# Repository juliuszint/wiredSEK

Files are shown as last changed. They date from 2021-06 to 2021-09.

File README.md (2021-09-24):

# A wired version of the Surface Ergonomic Keyboard from Microsoft.

## Disassembly
**Disclaimer**: These disassembly instructions can not be reversed and result in a broke keyboard. They are only provided as a documentation for other people to read, so that they dont have to brick their keyboard. So with that out of the way lets get started.

The keyboard is held together by an awful lot of glue and some screws. I do not own a heat gun and so i started with carefully using a screwdriver to remove the wrist rest. Even with a heat gun i doubt that it is impossible, to remove it without damaging some plastic. As can be seen in the following image, there is not only glue on the edges, but also in the center of the wrist rest.

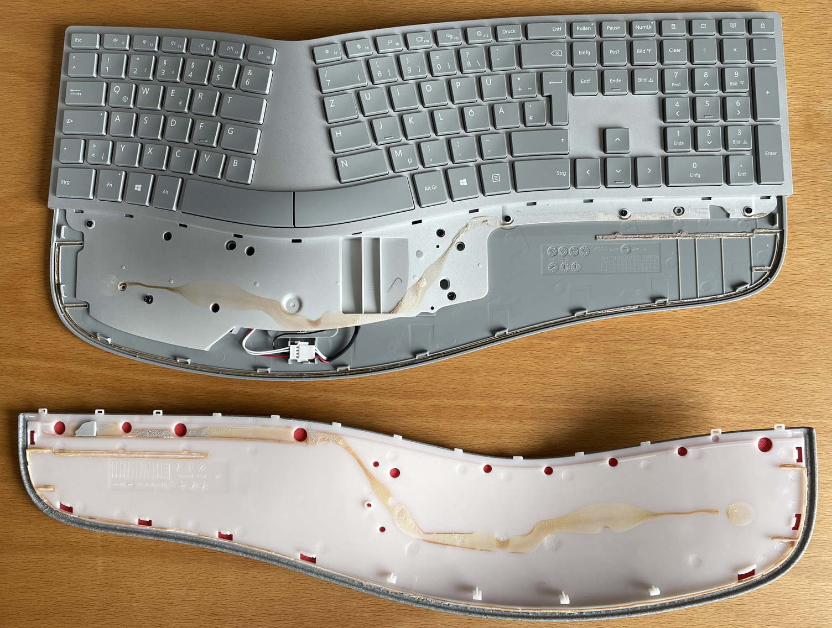
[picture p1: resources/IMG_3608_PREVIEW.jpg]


The next step is to remove all 10 screws. 4 of them are small and 6 are rather large and threaded into the plastic. Then disconnect the power and paring button connector from the logic board. Next up is getting the screw driver back out and start to remove the keyboard panel from the case. It is held in place by a glue stripe all around the edges, some glue right in the center of the keyboard, and 9 glue spots as one can see in the following image.

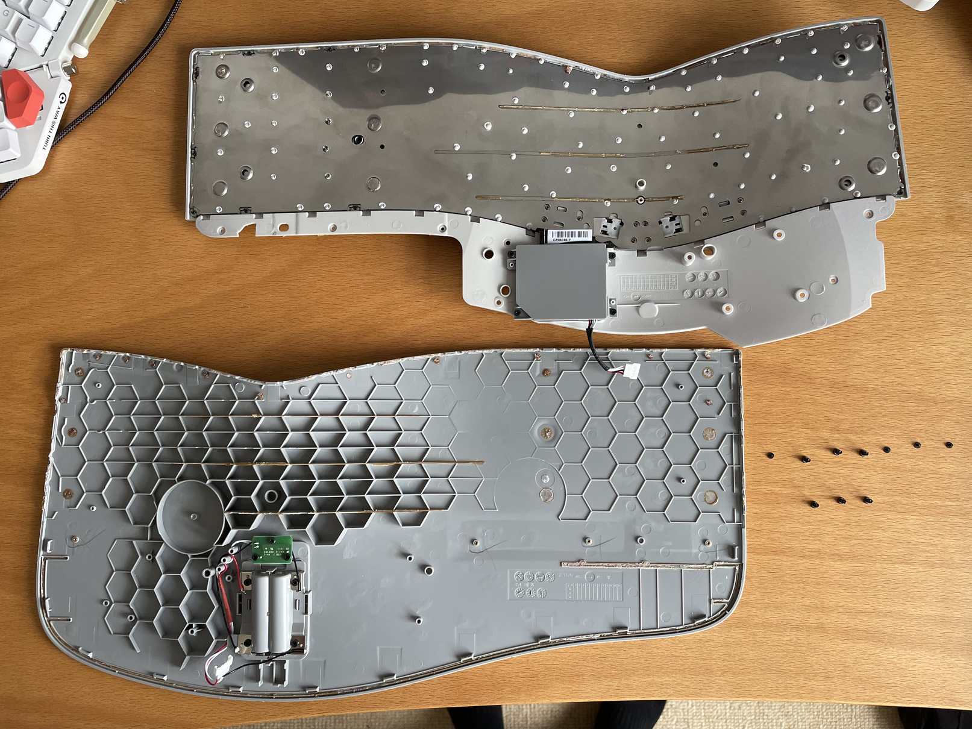
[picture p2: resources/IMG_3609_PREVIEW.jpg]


4 more large screws hold the logic board cover in place. With them removed we can lift up the logic board and see the 34 pin Flexible Flat Cable (FFC) that connects the keyboard matrix with the logic board. 2 of those 34 lanes are not routed, so only 32 are actually connected.

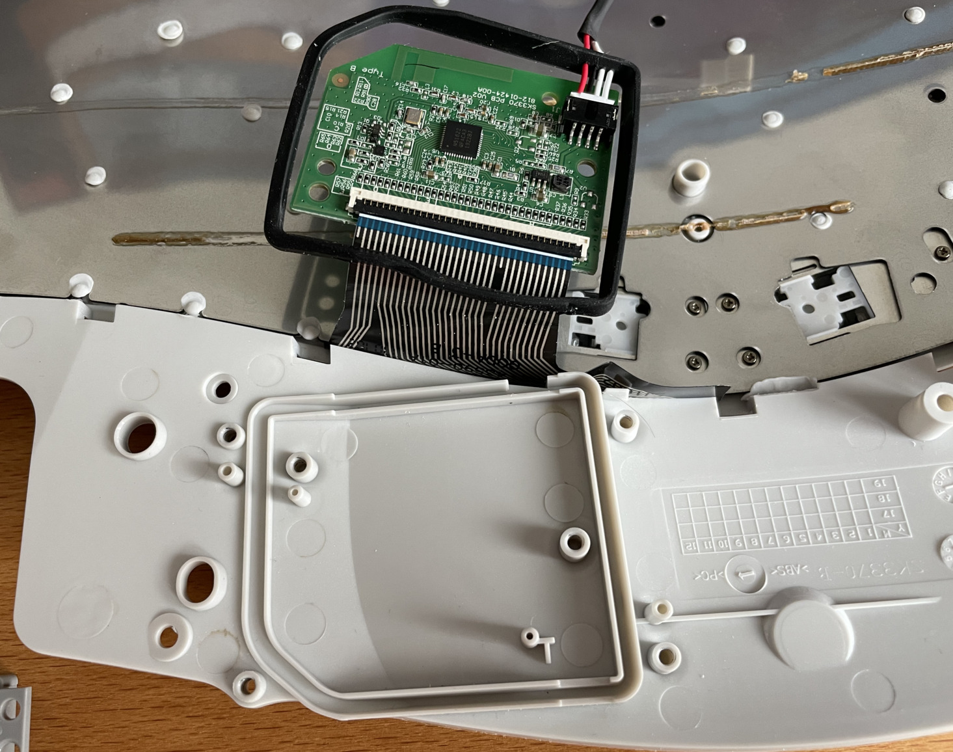
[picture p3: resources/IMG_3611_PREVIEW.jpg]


I hoped that by fully disassembling the keyboard, I would be able to learn more about the keyboard matrix, but this did not turn out to be true. Anyway, after i removed every single plastic rivet and removed the remaining screws, this is how a fully disassembled surface ergonomic keyboard looks like:

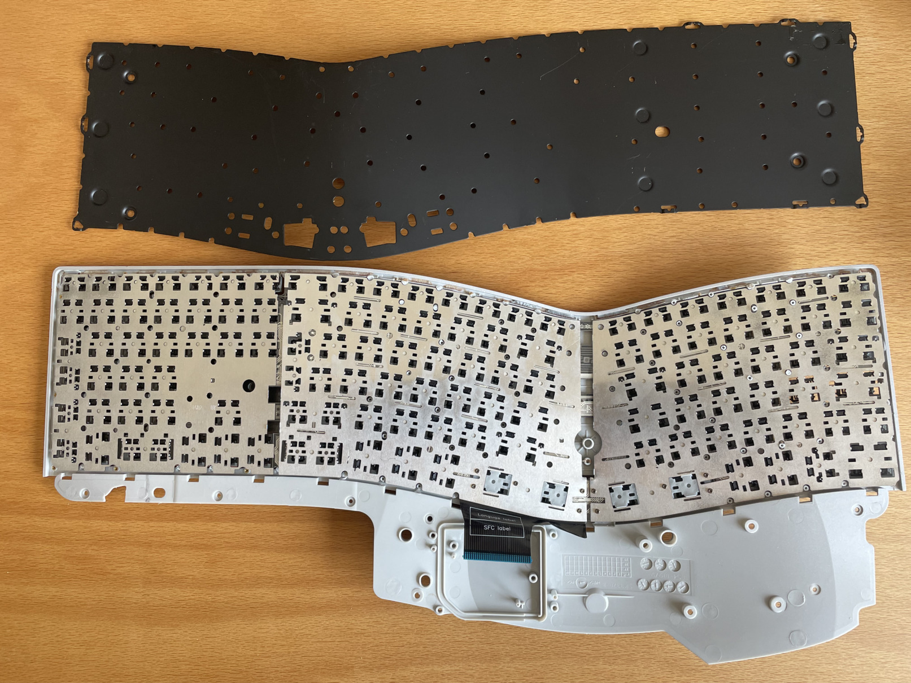
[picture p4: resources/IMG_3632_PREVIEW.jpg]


Once the metal backplate is removed, the keys can just be popped out. They are still kept in place by small metal sheets and the wires connecting them. With the keyboard fully disassembled, we can now start to measure the keyboard matrix.

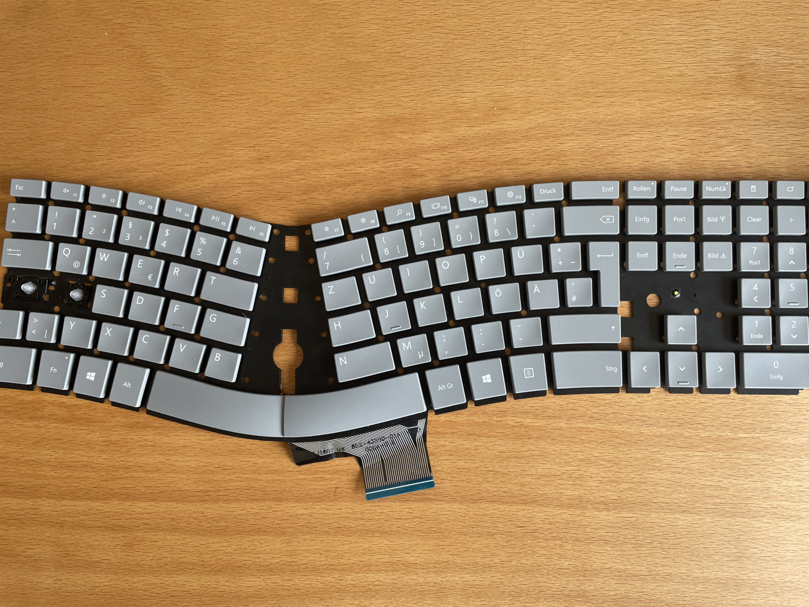
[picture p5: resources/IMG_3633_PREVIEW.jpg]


## Figuring out the keyboard matrix

With [@Geends](https://github.com/Geend/) logic analyzer and other hardware, we started by probing the logic level of every pin when no key is pressed. Next we toggled every LED (total of 4) one after another and observed the changes. Armed with that information we were able to make a educated guess of the keyboard matrix and with the 16 channel logic analyzer we were able to determine the full keyboard matrix.

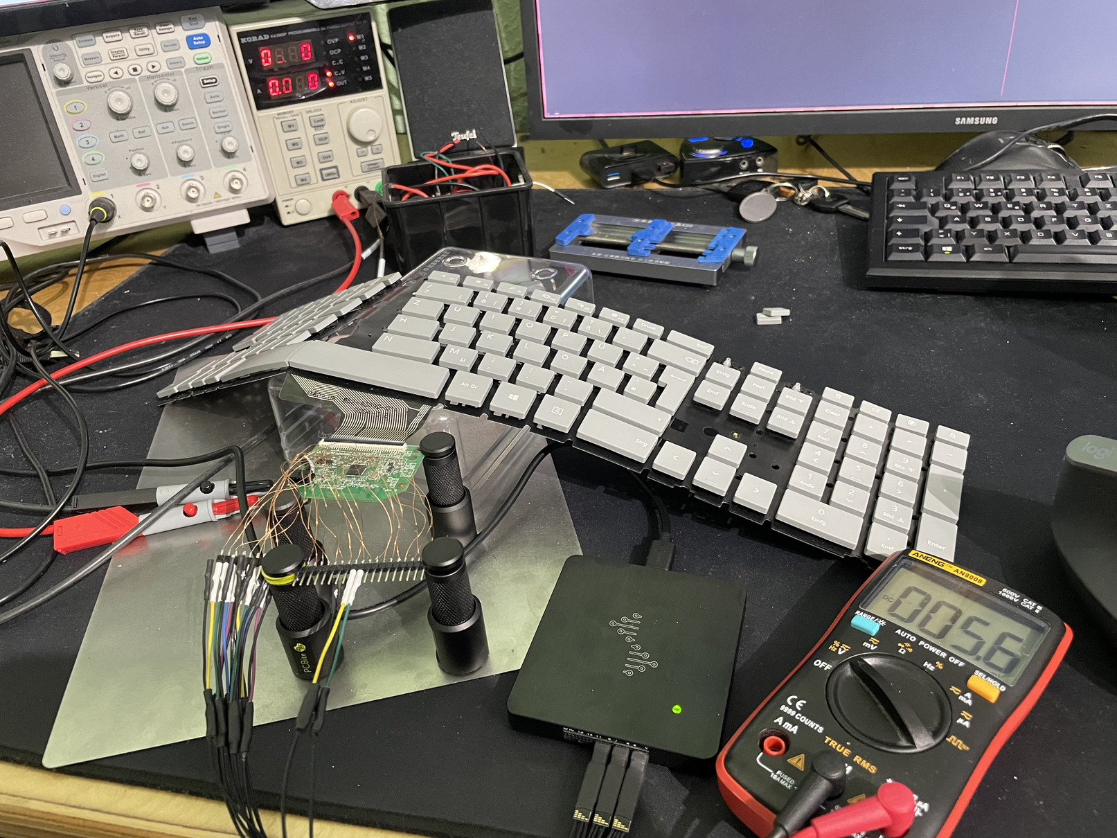
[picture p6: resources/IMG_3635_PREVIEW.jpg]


Initial testing results:

| Pin Number (top left = 0)| Logic Level without Keypress | Function |
|:---:|:---:| ---|
| 0 |3V | Keyboard Matrix: Row 0 |
| 1 |3V | Keyboard Matrix: Row 1 |
| 2 |3V | Keyboard Matrix: Row 2 |
| 3 |3V | Keyboard Matrix: Row 3 |
| 4 |3V | Keyboard Matrix: Row 4 |
| 5 |3V | Keyboard Matrix: Row 5 |
| 6 |3V | Keyboard Matrix: Row 6 |
| 7 |3V | Keyboard Matrix: Row 7 |
| 8 |3V | NumLink LED - with 3V the LED is off and on with 0.4V |
| 9 |3V | CapsLock LED - with 3V the LED is off and on with 0.4V |
| 10 |GND | Not connected |
| 11 |1V | Pairing LED - White |
| 12 |1V | Pairing LED - Red |
| 13 |3V | LED Vcc |
| 14 |0V | Keyboard Matrix: Column 0 |
| 15 |0V | Keyboard Matrix: Column 1 |
| 16 |0V | Keyboard Matrix: Column 2 |
| 17 |0V | Keyboard Matrix: Column 3 |
| 18 |0V | Keyboard Matrix: Column 4 |
| 19 |0V | Keyboard Matrix: Column 5 |
| 20 |0V | Keyboard Matrix: Column 6 |
| 21 |0V | Keyboard Matrix: Column 7 |
| 22 |0V | Keyboard Matrix: Column 8 |
| 23 |0V | Keyboard Matrix: Column 9 |
| 24 |0V | Keyboard Matrix: Column 10 |
| 25 |0V | Keyboard Matrix: Column 11 |
| 26 |0V | Keyboard Matrix: Column 12 |
| 27 |0V | Keyboard Matrix: Column 13 |
| 28 |0V | Keyboard Matrix: Column 14 |
| 29 |0V | Keyboard Matrix: Column 15 |
| 30 |0V | Keyboard Matrix: Column 16 |
| 31 |3V | Fn LED - with 3V the LED is off and on with 0.4V |
| 32 |3V | Rollen - with 3V the LED is off and on with 0.4V |
| 33 |GND | Not connected |

The keyboard matrix from Surface Ergonomic Keyboard with german keys:

| | Row-0 | Row-1 | Row-2 | Row-3 | Row-4 | Row-5 | Row-6 | Row-7 |
|:---:|:---:|:---:|:---:|:---:|:---:|:---:|:---:|:---:|
| Column-0  |Num Entf |Num 3 |Num 6 |Num 9 |Num \* |6 |V |L |
| Column-1  |Num 0 |Num 2 |Num 5 |Num 8 |Num / |5 |C |K |
| Column-2  |< |Num 1 |Num 4 |Num 7 |Calc |Num Enter |X |J |
| Column-3  |Y |T |R |E |W |Q |Pfeil oben  |H |
| Column-4  |- |Bild Unten  |Bild Hoch |Ende |Num Lock |Druck |F12 |Leer |
| Column-5  |. |F4 |Entf |Pos1 |Tab |Einfg |F11 |G |
| Column-6  |, |# |0 | |O |Num + |F10 |F |
| Column-7  |M |Ä |9 |+ |i |\` |F9 |D |
| Column-8  |N |Num - |8 |Ü |U |ß |F8 |S |
| Column-9  |Backspace |Arrow right |7 |P |Z |^ |F7 |A |
| Column-10 |Left Ctrl | | | |Right Ctrl  | | | |
| Column-11 | |Left Shift  | | | |Right Shift | |Fn |
| Column-12 | | |Left ALT | | | |Alt Gr |Context Menu|
| Column-13 |Pause |Rollen |Chat |Left WIN |Lock |Rechteck | |Right WIN |
| Column-14 |Num Clear |4 |F1 |F5 | |3 |Caps Lock |Arrow Down  |
| Column-15 | |F2 |F6 |Enter |F3 |2 | |Arrow Left  |
| Column-16 |Esc | | | | |1 |B |Ö |

## Designing the PCB

The most difficult part was to find a MCU due to the chip shortage. From all the compatible controllers that are listed on QMKs website only the AT90USB646 was available. This turned out to be a perfect fit. It is a very simple MCU with enough GPIO pins, USB and a 64-TQFP package can be soldered by hand.

There is not much to say about the schematic itself because there is not a lot more on it then the MCU and a USB jack. There are a lot of testpoints, a power LED that can be disabled with a solder jumper, a status LED and a JTAG interface.

The complete board was designed with the open source software Kicad and tutorials from the Youtube channel Phil's Lab. This [[2]] three hour video is a great resource if someone wants to learn how to create a board from scratch and have it manufactured.

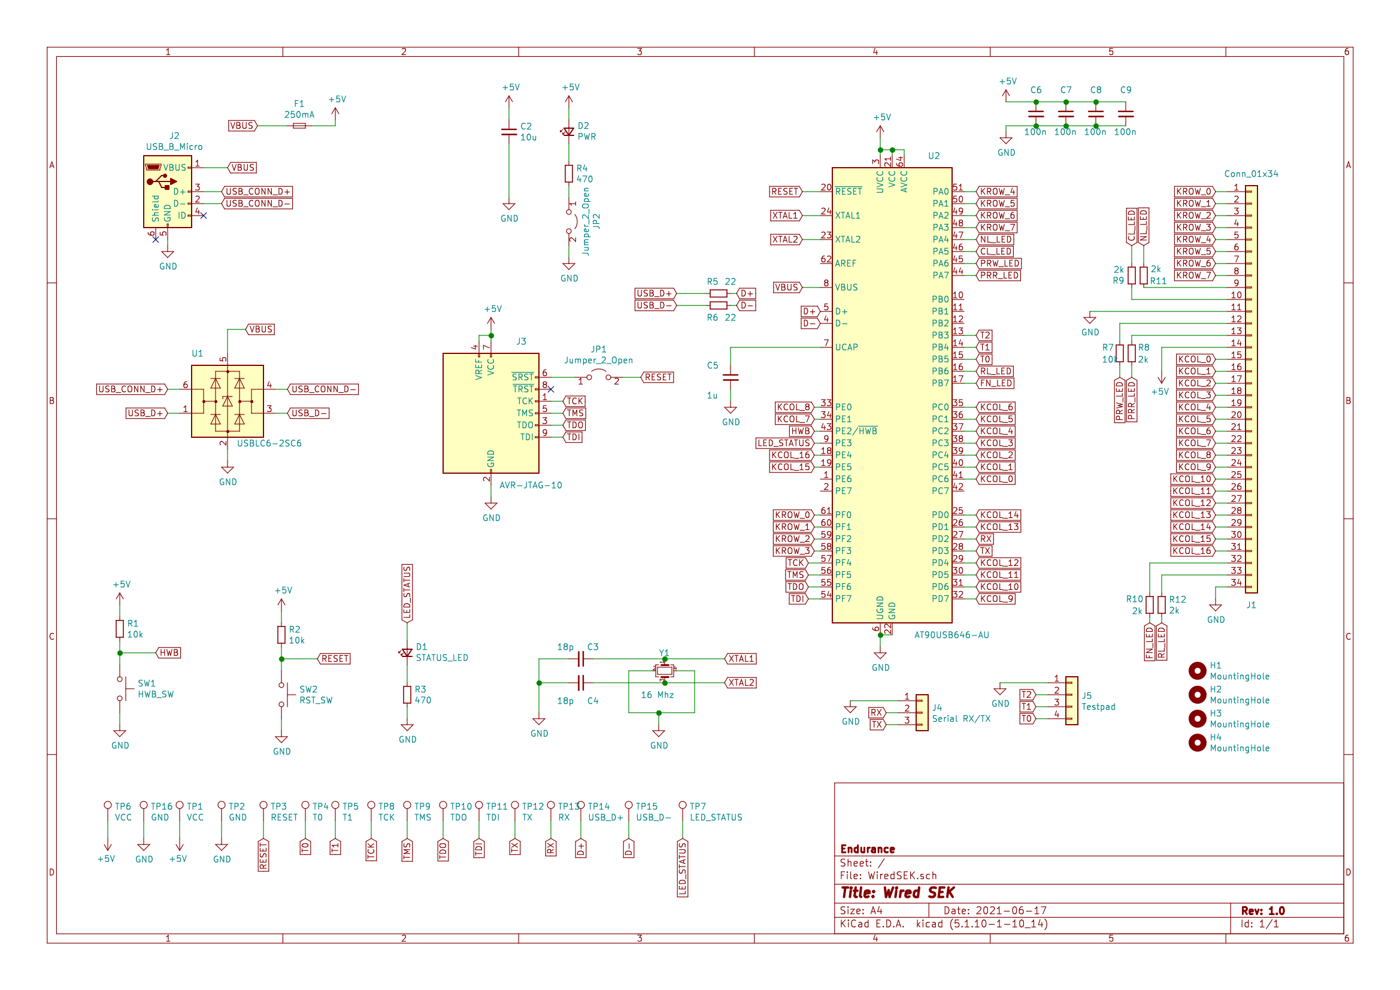
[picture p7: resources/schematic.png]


The outline and four holes (two placeholder and two for screws) are required for the circuit board to fit inside the keyboard. The position of the FFC/FPC connector is also fixed while the rest is up to us. 

The USB connector was the most difficult part to place. Because the keyboard is glued together and cannot be easily opened without damaging it, the plan is to make a small cutout where the PCB is located. So in a perfect world the connector would not need any more space than what is neccessary to switch the board. I managed this by using a right angle USB connector on the back of the PCB.

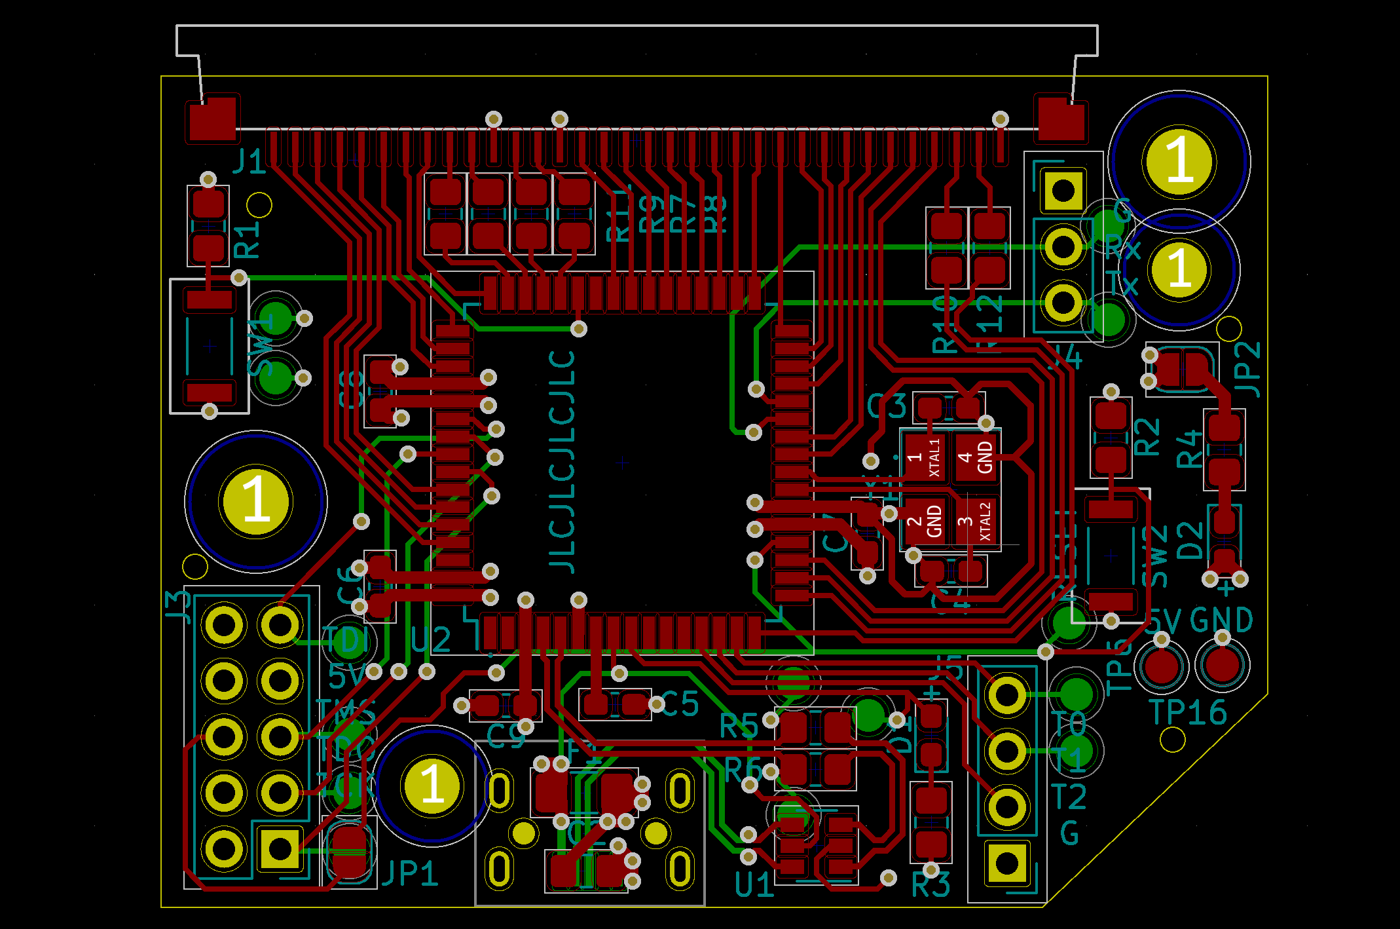
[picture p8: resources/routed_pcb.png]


## PCB assembly

The USB connector, the FFC/FPC connector and the MCU had to be soldered by hand. Everything else was done by JLCPCB. These were the exact parts that i ordered. I included the USB cable not only because i like completeness, but also because not every cable will work. Between the USB connector and the PCB is only a limited amount of space for the plug.

* [FFC/FPC Connector](https://www.digikey.de/product-detail/de/F52R-1A7H1-11034/609-F52R-1A7H1-11034DKR-ND/11564783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)
* [AT90USB646-AUR](https://www.digikey.de/product-detail/de/microchip-technology/AT90USB646-AUR/AT90USB646-AURCT-ND/3789393)
* [Micro USB Receptacle](https://www.digikey.de/product-detail/de/amphenol-icc-commercial-products/GMCB05801124EU/664-GMCB05801124EUTR-ND/13683048)
* [USB-Cabel](https://www.otto.de/p/primewire-premium-micro-usb-auf-usb-kabel-usb-a-stecker-auf-micro-b-stecker-600433312/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)

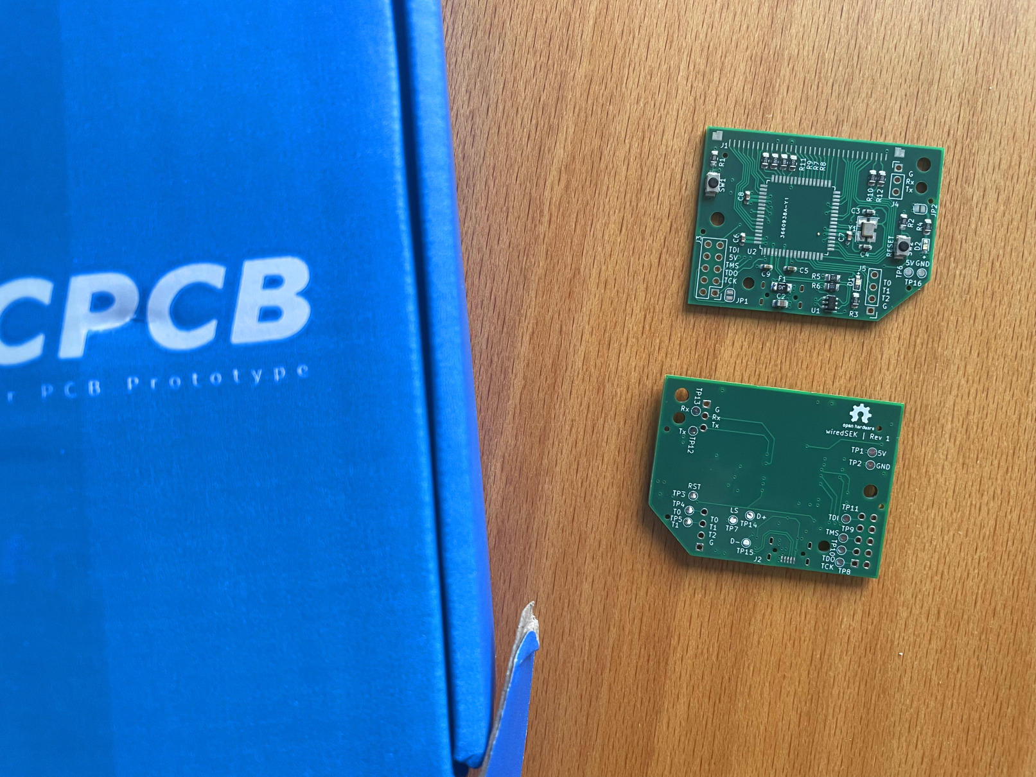
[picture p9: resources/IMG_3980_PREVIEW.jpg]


## Keyboard (dis)assembly

Now we need a way to put our new PCB in. The `mask.odg` document contains a template that i used to mark the exact cutout. I printed it, glued it to cardboard and then used a box cutter to finish the stencil. To align it just use the side with the angled corners, put them into the battery compartment and then draw the inner lines. The rectangle at the top marks the position where the Flexible Flat Cable runs. In my first attempt this was not there and i bricked a keyboard :(. So to make sure this wont happen again, its important to first leave it there and after removing the rest, very carefully start to remove it by cutting only to a third of the depth and then break it.

The only thing left is to remove the PCB cover. There are 4 screws in total holding it in place. Two of which we can just open and then we have to just remove it by pulling up on the left side until the two arms on the right side break (does not take that much force).

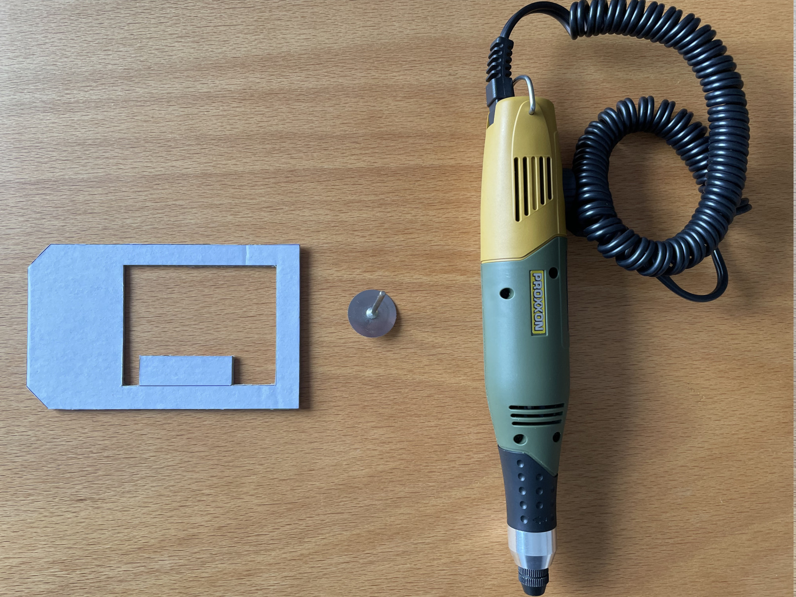
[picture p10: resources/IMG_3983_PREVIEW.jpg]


## Firmware

Quantum Mechanical Keyboard (QMK) Firmware [[3]] is, as the name suggests, an open source firmware for keyboards. It powers the Moonlander and ErgoDoxEZ from ZSA and in general is super awesome and easy to customize. Even for completly custom keyboards like this one it is incredibly easy to get started.

The added code can be found in my fork of the QMK repository on the wiredSEK branch. Basically the changes boil down to adding a new directory `keyboards/handwired/wiredSEK` and filling it with code that tells QMK what MCU it will be running on, which pins are connected to the keyboard matrix and what the keyboard layout should look like.

Everything that is left to do is to compile and flash the firmware with the follwing commands:
```
# compile
qmk compile -kb handwired/wiredsek -km default

# flash
sudo dfu-programmer at90usb646 erase --force
sudo dfu-programmer at90usb646 flash handwired_wiredsek_default.hex
sudo dfu-programmer at90usb646 launch
```

## The finished Keyboard

The only remaining question should be: **Why?** I would be lying if i told you that this project was not fun for me but this is not the only reason. As a programmer you type **a lot**. It therefore makes perfect sense to spend some time and optimize the device that you use to insert every single character.

I stopped counting the keyboards that i used. From a 10$ standard Logitech keyboard up to a Moonlander from ZSA i tried pretty much everything. The Surface Ergnomic Keyboard from Microsoft and the Moonlander from ZSA were the ones i liked the most, sadly for different reasons.

The Alcantara wrist rest, the keytravel, the switches and the ergonomic layout are the things that i enjoyed most while using the keyboard from Microsoft. Obviously the biggest downside for me was that it only connected via Bluetooth. It was laggy, could only be connected to a single computer and if you did not type for a few seconds, the keyboard went directly to sleep and it takes about a second for it to wake up while forgetting the key you pressed. Very annoying.

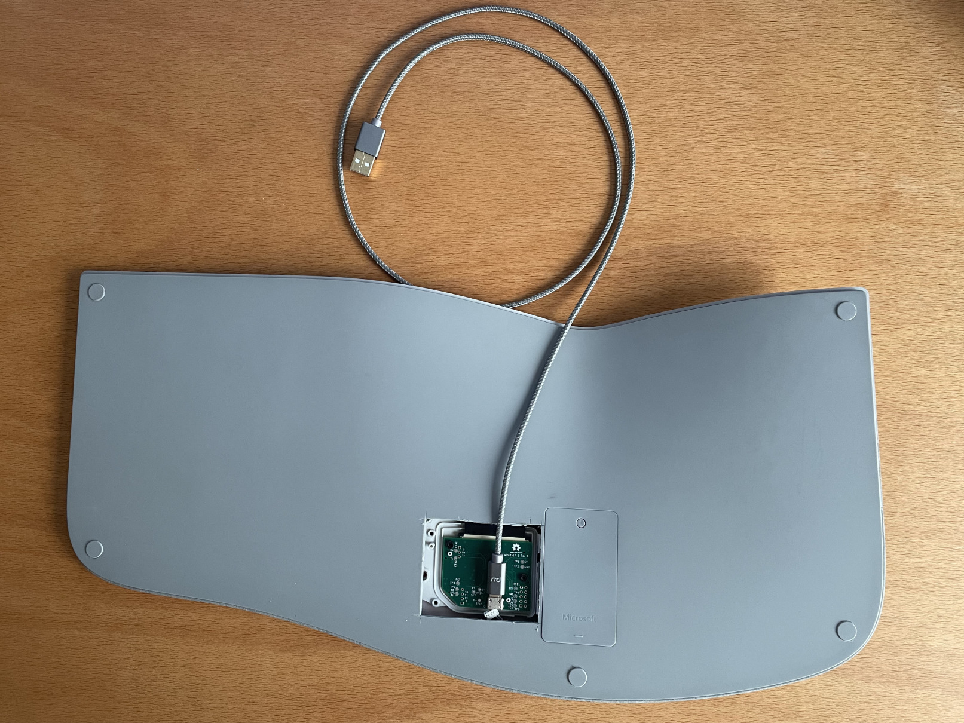
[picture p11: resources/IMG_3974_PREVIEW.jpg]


## Related Work
Chad Austin made a wired version of the Sculpt Ergonomic Keyboard [[1]].
 
[1]: https://chadaustin.me/2021/02/wired-sculpt/
[2]: https://www.youtube.com/watch?v=C7-8nUU6e3E
[3]: https://docs.qmk.fm/#/

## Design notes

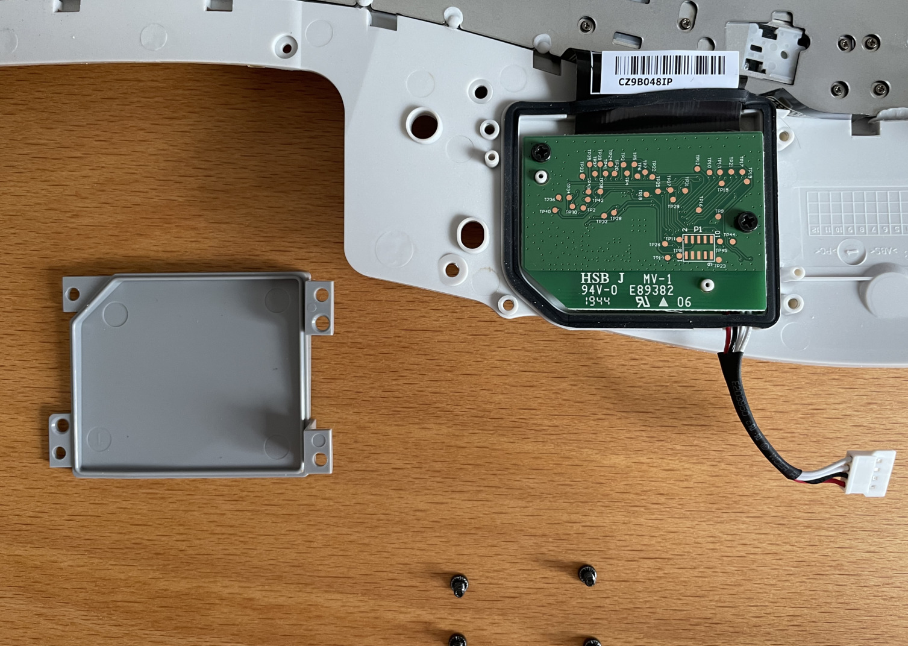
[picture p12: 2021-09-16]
resources/IMG_3610_PREVIEW.jpg

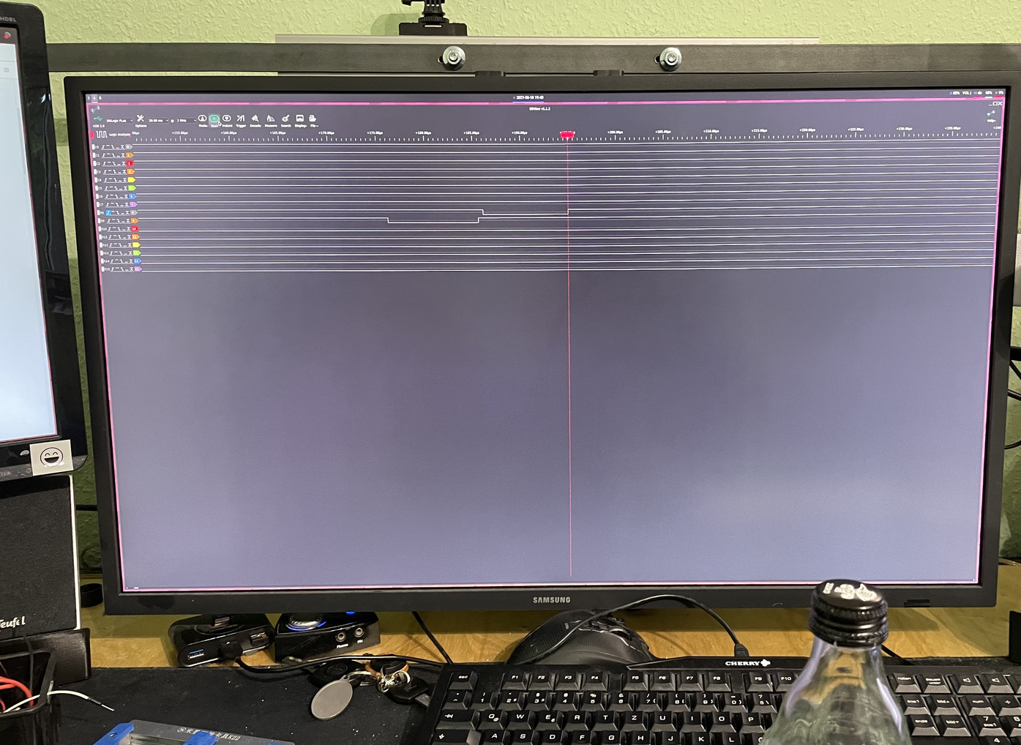
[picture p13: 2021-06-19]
resources/IMG_3636_PREVIEW.jpg

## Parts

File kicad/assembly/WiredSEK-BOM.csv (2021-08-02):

Comment | Designator | Footprint | LCSC
10u | C2 | Capacitor_SMD:C_0805_2012Metric_Pad1.18x1.45mm_HandSolder | C15850
18p | C3,C4 | Capacitor_SMD:C_0603_1608Metric_Pad1.08x0.95mm_HandSolder | C1647
1u | C5 | Capacitor_SMD:C_0603_1608Metric_Pad1.08x0.95mm_HandSolder | C15849
100n | C6,C7,C8,C9 | Capacitor_SMD:C_0603_1608Metric_Pad1.08x0.95mm_HandSolder | C57112
STATUS_LED | D1 | LED_SMD:LED_0603_1608Metric_Pad1.05x0.95mm_HandSolder | C72041
PWR | D2 | LED_SMD:LED_0603_1608Metric_Pad1.05x0.95mm_HandSolder | C72043
250mA | F1 | Fuse:Fuse_1206_3216Metric_Pad1.42x1.75mm_HandSolder | C369159
MountingHole | H1,H2 | MountingHole:MountingHole_3mm
MountingHole | H3,H4 | MountingHole:MountingHole_2.5mm
Conn_01x34 | J1 | WiredSEK:F52R-1A7H1-11034
USB_B_Micro | J2 | WiredSEK:GMCB05801124EU
AVR-JTAG-10 | J3 | Connector_PinHeader_2.54mm:PinHeader_2x05_P2.54mm_Vertical
Serial RX/TX | J4 | Connector_PinHeader_2.54mm:PinHeader_1x03_P2.54mm_Vertical
Testpad | J5 | Connector_PinHeader_2.54mm:PinHeader_1x04_P2.54mm_Vertical
Jumper_2_Open | JP1,JP2 | Jumper:SolderJumper-2_P1.3mm_Open_RoundedPad1.0x1.5mm
2k | R8,R9,R10,R11,R12 | Resistor_SMD:R_0805_2012Metric_Pad1.20x1.40mm_HandSolder | C17710
10k | R1,R2,R7 | Resistor_SMD:R_0805_2012Metric_Pad1.20x1.40mm_HandSolder | C17414
470 | R3,R4 | Resistor_SMD:R_0805_2012Metric_Pad1.20x1.40mm_HandSolder | C17710
22 | R5,R6 | Resistor_SMD:R_0805_2012Metric_Pad1.20x1.40mm_HandSolder | C25295
HWB_SW | SW1 | WiredSEK:SKRKAEE020 | C115357
RST_SW | SW2 | WiredSEK:SKRKAEE020 | C115357
VCC | TP1,TP6 | TestPoint:TestPoint_Pad_D1.5mm
TDO | TP10 | TestPoint:TestPoint_Pad_D1.5mm
TDI | TP11 | TestPoint:TestPoint_Pad_D1.5mm
TX | TP12 | TestPoint:TestPoint_Pad_D1.5mm
RX | TP13 | TestPoint:TestPoint_Pad_D1.5mm
USB_D+ | TP14 | TestPoint:TestPoint_Pad_D1.5mm
USB_D- | TP15 | TestPoint:TestPoint_Pad_D1.5mm
GND | TP2,TP16 | TestPoint:TestPoint_Pad_D1.5mm
RESET | TP3 | TestPoint:TestPoint_Pad_D1.5mm
T0 | TP4 | TestPoint:TestPoint_Pad_D1.5mm
T1 | TP5 | TestPoint:TestPoint_Pad_D1.5mm
LED_STATUS | TP7 | TestPoint:TestPoint_Pad_D1.5mm
TCK | TP8 | TestPoint:TestPoint_Pad_D1.5mm
TMS | TP9 | TestPoint:TestPoint_Pad_D1.5mm
USBLC6-2SC6 | U1 | Package_TO_SOT_SMD:SOT-23-6 | C558442
AT90USB646-AU | U2 | Package_QFP:TQFP-64_14x14mm_P0.8mm
16 Mhz | Y1 | Crystal:Crystal_SMD_3225-4Pin_3.2x2.5mm_HandSoldering | C13738

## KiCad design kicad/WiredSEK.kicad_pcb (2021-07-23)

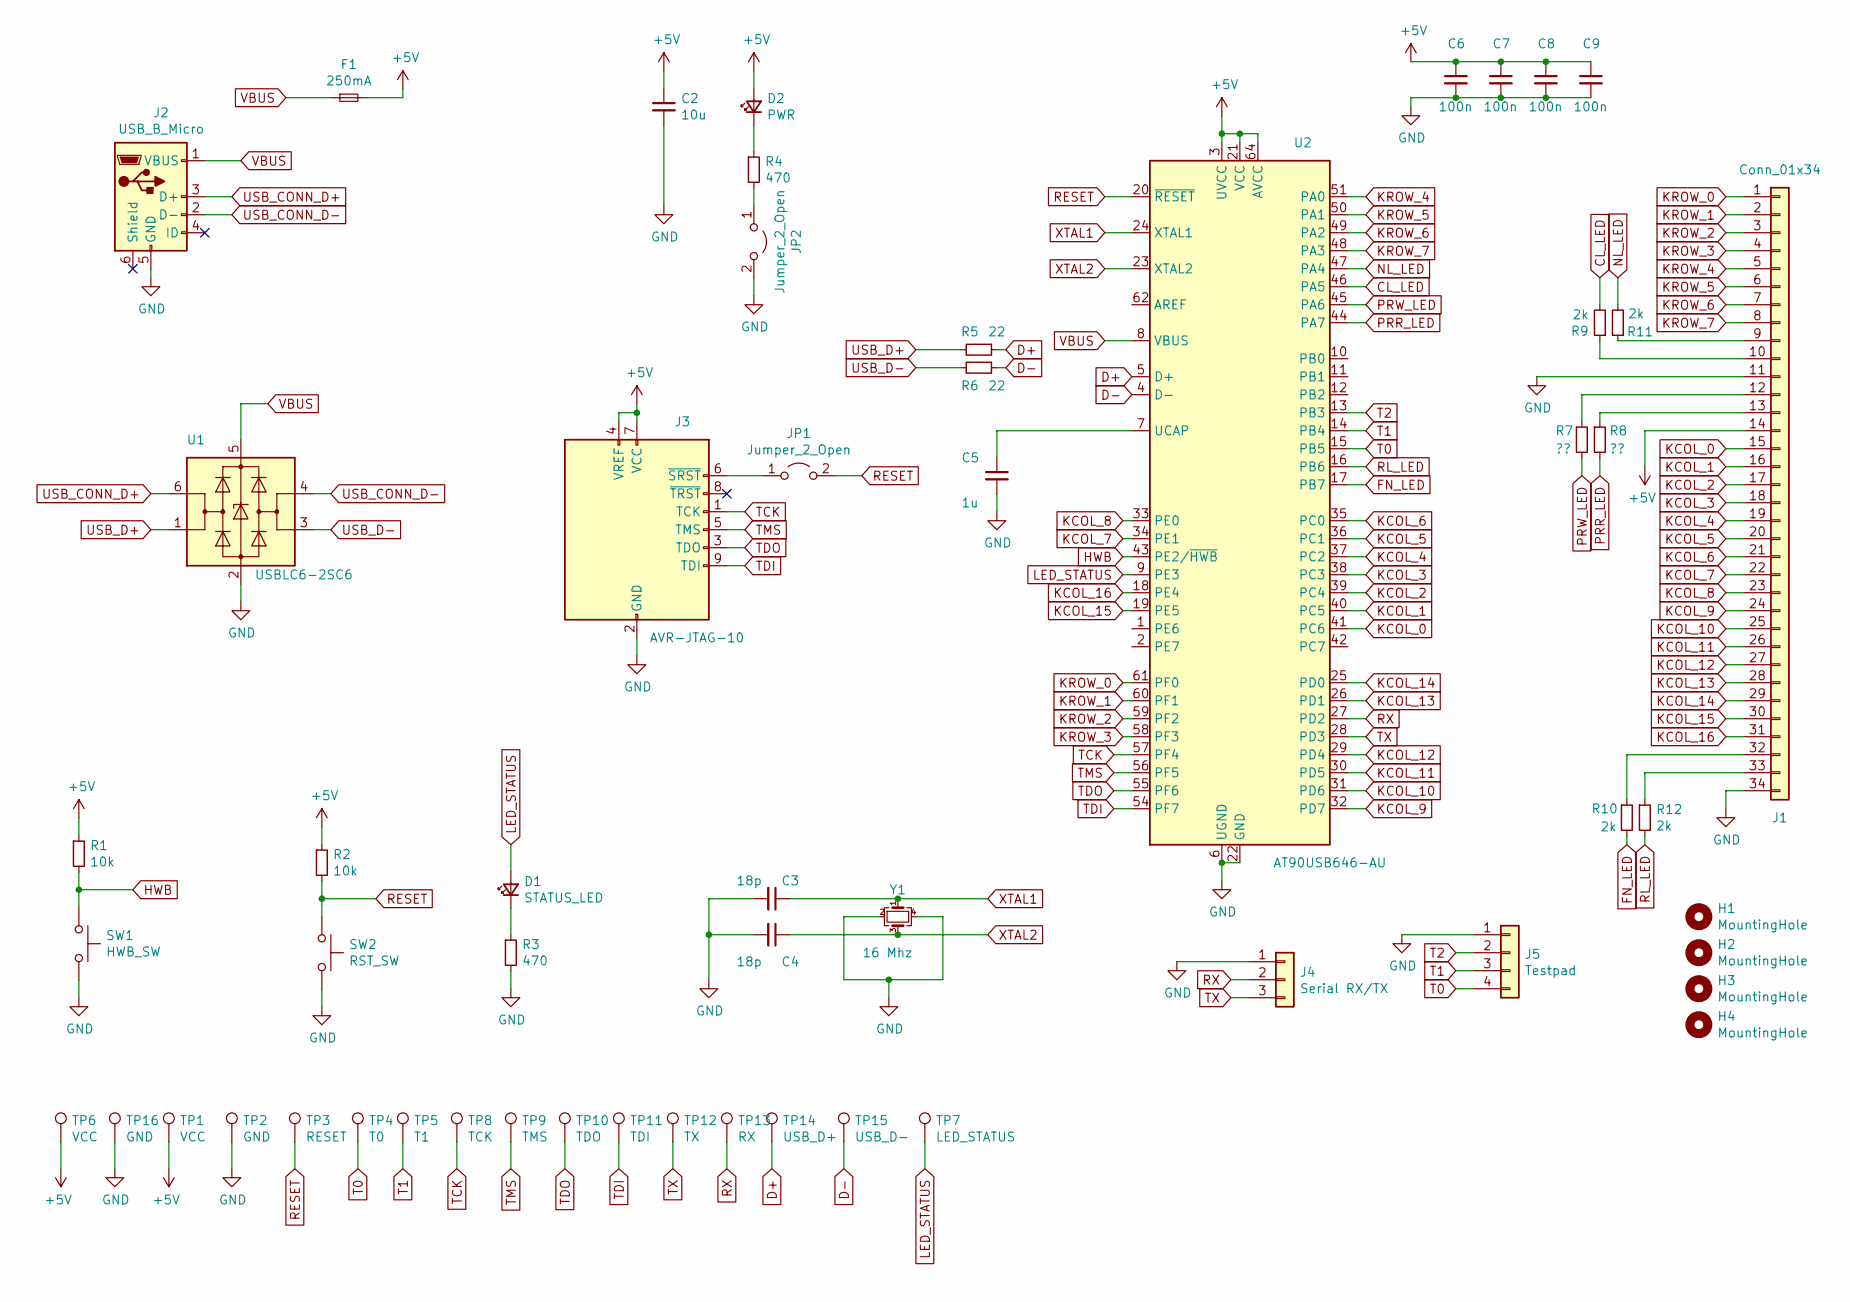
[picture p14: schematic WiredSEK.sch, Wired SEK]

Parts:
C2: 10u; C_0805_2012Metric_Pad1.18x1.45mm_HandSolder; LCSC Part # C15850
C3, C4: 18p; C_0603_1608Metric_Pad1.08x0.95mm_HandSolder; LCSC Part # C1647
C5: 1u; C_0603_1608Metric_Pad1.08x0.95mm_HandSolder; LCSC Part # C15849
C6, C7, C8, C9: 100n; C_0603_1608Metric_Pad1.08x0.95mm_HandSolder; LCSC Part # C57112
D1: STATUS_LED; LED_0603_1608Metric_Pad1.05x0.95mm_HandSolder; LCSC Part # C72041
D2: PWR; LED_0603_1608Metric_Pad1.05x0.95mm_HandSolder; LCSC Part # C72043
F1: 250mA; Fuse_1206_3216Metric_Pad1.42x1.75mm_HandSolder; LCSC Part # C369159
H1, H2: MountingHole; MountingHole_3mm
H3, H4: MountingHole; MountingHole_2.5mm
J1: Conn_01x34; F52R-1A7H1-11034
J2: USB_B_Micro; GMCB05801124EU
J3: AVR-JTAG-10; PinHeader_2x05_P2.54mm_Vertical
J4: Serial RX/TX; PinHeader_1x03_P2.54mm_Vertical
J5: Testpad; PinHeader_1x04_P2.54mm_Vertical
JP1, JP2: Jumper_2_Open; SolderJumper-2_P1.3mm_Open_RoundedPad1.0x1.5mm
R1, R2: 10k; R_0805_2012Metric_Pad1.20x1.40mm_HandSolder; LCSC Part # C17414
R3, R4: 470; R_0805_2012Metric_Pad1.20x1.40mm_HandSolder; LCSC Part # C17710
R5, R6: 22; R_0805_2012Metric_Pad1.20x1.40mm_HandSolder; LCSC Part # C25295
R7, R8: ??; R_0805_2012Metric_Pad1.20x1.40mm_HandSolder
R9, R10, R11, R12: 2k; R_0805_2012Metric_Pad1.20x1.40mm_HandSolder; LCSC Part # C17710
SW1: HWB_SW; SKRKAEE020; LCSC Part # C115357
SW2: RST_SW; SKRKAEE020; LCSC Part # C115357
TP1, TP6: VCC; TestPoint_Pad_D1.5mm
TP2, TP16: GND; TestPoint_Pad_D1.5mm
TP3: RESET; TestPoint_Pad_D1.5mm
TP4: T0; TestPoint_Pad_D1.5mm
TP5: T1; TestPoint_Pad_D1.5mm
TP7: LED_STATUS; TestPoint_Pad_D1.5mm
TP8: TCK; TestPoint_Pad_D1.5mm
TP9: TMS; TestPoint_Pad_D1.5mm
TP10: TDO; TestPoint_Pad_D1.5mm
TP11: TDI; TestPoint_Pad_D1.5mm
TP12: TX; TestPoint_Pad_D1.5mm
TP13: RX; TestPoint_Pad_D1.5mm
TP14: USB_D+; TestPoint_Pad_D1.5mm
TP15: USB_D-; TestPoint_Pad_D1.5mm
U1: USBLC6-2SC6; SOT-23-6; LCSC Part # C558442
U2: AT90USB646-AU; TQFP-64_14x14mm_P0.8mm
Y1: 16 Mhz; Crystal_SMD_3225-4Pin_3.2x2.5mm_HandSoldering; LCSC Part # X1E000021011900

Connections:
+5V: C2.1, C6.1, C7.1, C8.1, C9.1, D2.2 (A), F1.2, J1.14, J3.4 (VREF), J3.7 (VCC), R1.1, R2.1, TP1.1, TP6.1, U2.3 (UVCC), U2.21 (VCC), U2.52 (VCC), U2.64 (AVCC)
CL_LED: R9.2, U2.46 (PA5)
D+: R5.1, TP14.1, U2.5 (D+)
D-: R6.1, TP15.1, U2.4 (D-)
FN_LED: R10.2, U2.17 (PB7)
GND: C2.2, C3.2, C4.2, C5.2, C6.2, C7.2, C8.2, C9.2, J1.11, J1.34, J2.5 (GND), J3.2 (GND), J3.10 (GND), J4.1, J5.1, JP2.2 (B), R3.2, SW1.2, SW2.2, TP2.1, TP16.1, U1.2 (GND), U2.6 (UGND), U2.22 (GND), U2.53 (GND), U2.63 (GND), Y1.2, Y1.4
HWB: R1.2, SW1.1, U2.43 (PE2/~HWB)
KCOL_0: J1.15, U2.41 (PC6)
KCOL_1: J1.16, U2.40 (PC5)
KCOL_2: J1.17, U2.39 (PC4)
KCOL_3: J1.18, U2.38 (PC3)
KCOL_4: J1.19, U2.37 (PC2)
KCOL_5: J1.20, U2.36 (PC1)
KCOL_6: J1.21, U2.35 (PC0)
KCOL_7: J1.22, U2.34 (PE1)
KCOL_8: J1.23, U2.33 (PE0)
KCOL_9: J1.24, U2.32 (PD7)
KCOL_10: J1.25, U2.31 (PD6)
KCOL_11: J1.26, U2.30 (PD5)
KCOL_12: J1.27, U2.29 (PD4)
KCOL_13: J1.28, U2.26 (PD1)
KCOL_14: J1.29, U2.25 (PD0)
KCOL_15: J1.30, U2.19 (PE5)
KCOL_16: J1.31, U2.18 (PE4)
KROW_0: J1.1, U2.61 (PF0)
KROW_1: J1.2, U2.60 (PF1)
KROW_2: J1.3, U2.59 (PF2)
KROW_3: J1.4, U2.58 (PF3)
KROW_4: J1.5, U2.51 (PA0)
KROW_5: J1.6, U2.50 (PA1)
KROW_6: J1.7, U2.49 (PA2)
KROW_7: J1.8, U2.48 (PA3)
LED_STATUS: D1.2 (A), TP7.1, U2.9 (PE3)
NL_LED: R11.2, U2.47 (PA4)
unnamed: C5.1, U2.7 (UCAP)
unnamed: D1.1 (K), R3.1
unnamed: D2.1 (K), R4.1
unnamed: J1.9, R11.1
unnamed: J1.10, R9.1
unnamed: J1.12, R7.1
unnamed: J1.13, R8.1
unnamed: J1.32, R10.1
unnamed: J1.33, R12.1
unnamed: J3.6 (~SRST), JP1.1 (A)
unnamed: JP2.1 (A), R4.2
PRR_LED: R8.2, U2.44 (PA7)
PRW_LED: R7.2, U2.45 (PA6)
RESET: JP1.2 (B), R2.2, SW2.1, TP3.1, U2.20 (~RESET)
RL_LED: R12.2, U2.16 (PB6)
RX: J4.2, TP13.1, U2.27 (PD2)
T0: J5.4, TP4.1, U2.15 (PB5)
T1: J5.3, TP5.1, U2.14 (PB4)
T2: J5.2, U2.13 (PB3)
TCK: J3.1 (TCK), TP8.1, U2.57 (PF4)
TDI: J3.9 (TDI), TP11.1, U2.54 (PF7)
TDO: J3.3 (TDO), TP10.1, U2.55 (PF6)
TMS: J3.5 (TMS), TP9.1, U2.56 (PF5)
TX: J4.3, TP12.1, U2.28 (PD3)
USB_CONN_D+: J2.3 (D+), U1.6 (I/O1)
USB_CONN_D-: J2.2 (D-), U1.4 (I/O2)
USB_D+: R5.2, U1.1 (I/O1)
USB_D-: R6.2, U1.3 (I/O2)
VBUS: F1.1, J2.1 (VBUS), U1.5 (VBUS), U2.8 (VBUS)
XTAL1: C3.1, U2.24 (XTAL1), Y1.1
XTAL2: C4.1, U2.23 (XTAL2), Y1.3

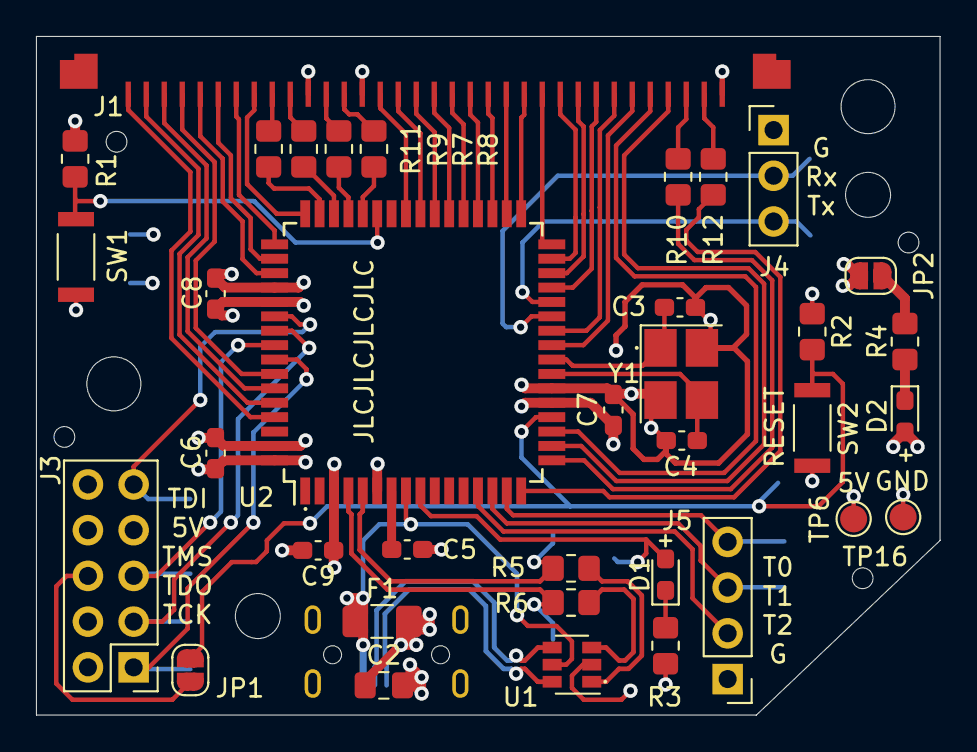
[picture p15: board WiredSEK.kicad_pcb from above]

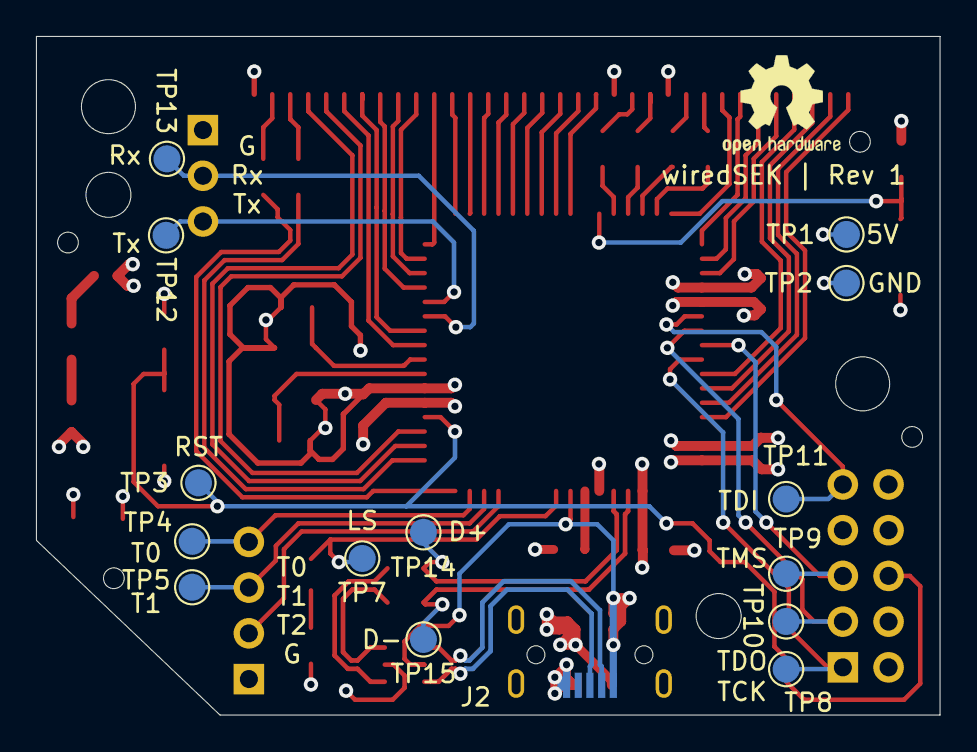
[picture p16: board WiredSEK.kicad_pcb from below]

Board: 4 copper layers, 50.2 x 37.7 mm, 55 parts (15 on the bottom side), 65 nets.

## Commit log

2021-06-18 moved kicad files out of subfolder
    [WiredSEK.kicad_pcb, WiredSEK.sch]
2021-07-17 fixed typo, switched row and column, and added more information after new reverse engineering session
2021-07-18 done with pcb routing
    [WiredSEK.kicad_pcb, WiredSEK.sch]
2021-07-21 Fixed SW1 and SW2 footprints and cleaned silk layers
    [WiredSEK.kicad_pcb]
2021-07-23 preparing for jlcpcb order
    [WiredSEK.kicad_pcb, WiredSEK.sch]
2021-07-23 added pin 1 and polarity markers
    [WiredSEK.kicad_pcb]
2021-07-23 switched row and column in secondary table
2021-08-02 JLCPCB Order REV 1
    [WiredSEK-BOM.csv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]
2021-09-09 switched column 2 and 3 after testing
2021-09-14 added small sample c program for testing the board
2021-09-15 added the pcb section
2021-09-22 keyboard (dis)assembly
